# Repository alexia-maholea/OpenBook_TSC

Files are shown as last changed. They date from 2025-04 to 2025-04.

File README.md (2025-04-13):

# OpenBook E-Reader
Maholea Elena-Alexia, 333CD

## Viziune de ansamblu a proiectului
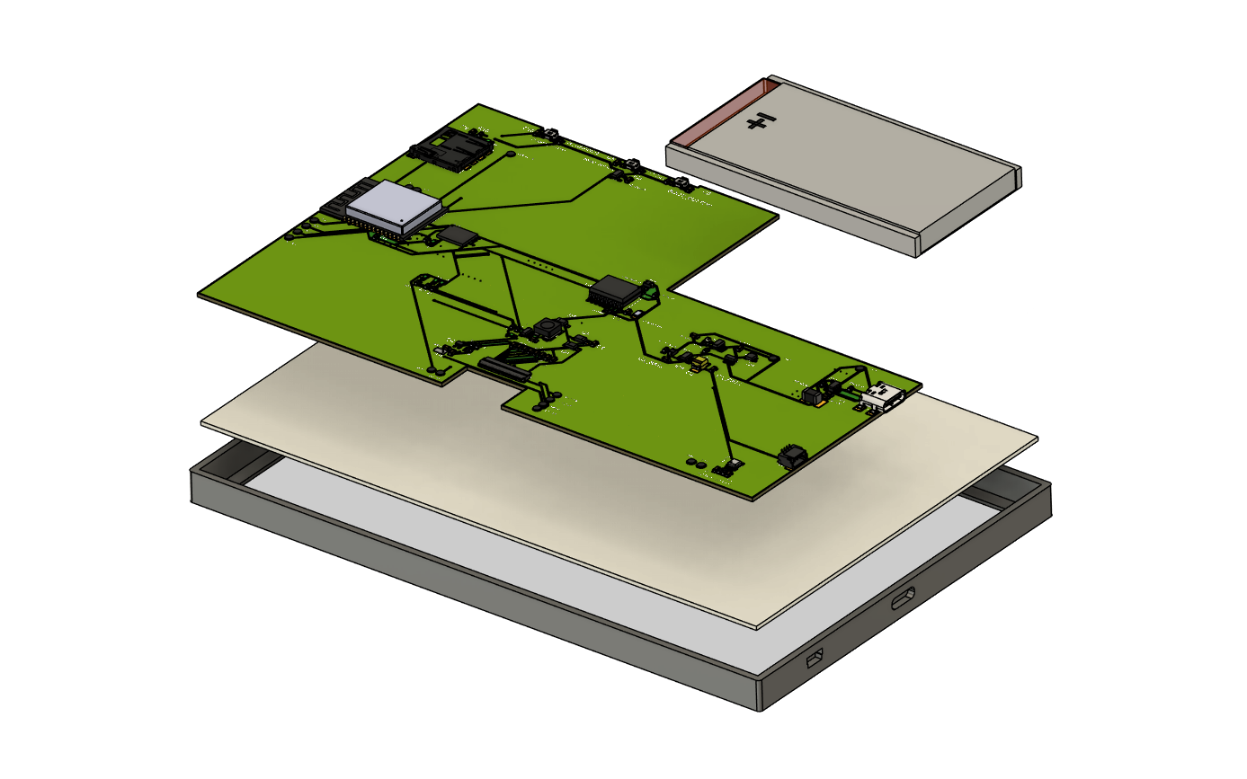
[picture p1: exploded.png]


## Schema bloc
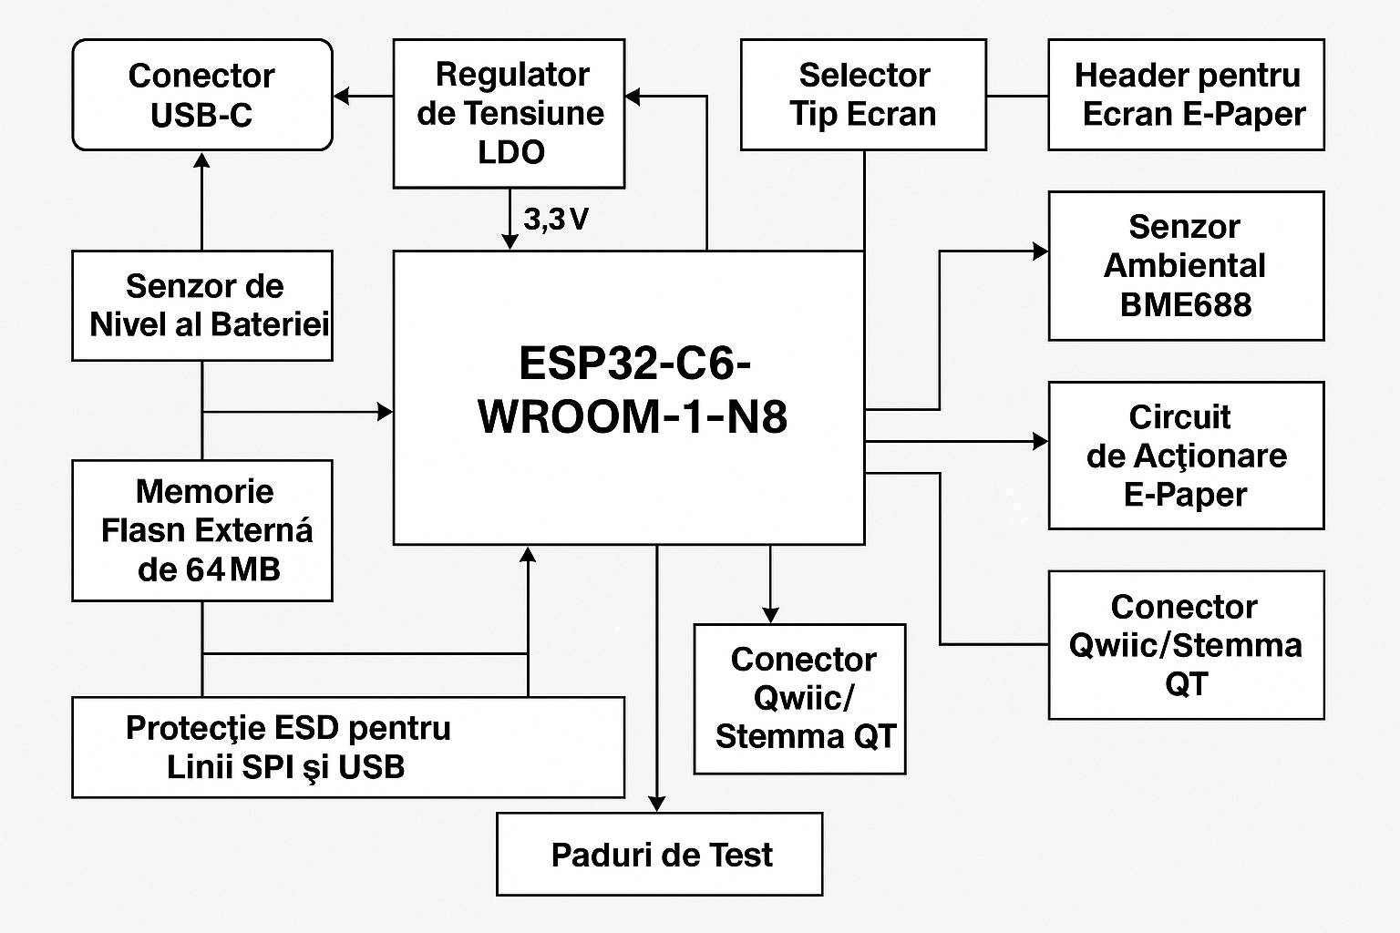
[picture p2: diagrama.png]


# Bill of Materials
|**Part Name** | **Check Price** | **DataSheet** |
|---|---|---|
|BUTTON| [Check Price](https://industry.panasonic.com/global/en/products/control/switch/light-touch/number/evqpuj02k) | [DataSheet](https://industry.panasonic.com/global/en/products/control/switch/light-touch/number/evqpuj02k) 
| ESP32_WROVER_EAGLE-LTSPICE_CC0402 | [Check Price](https://componentsearchengine.com/part-view/CC0402MRX5R5BB106/YAGEO) | [DataSheet](https://componentsearchengine.com/part-view/CC0402MRX5R5BB106/YAGEO) |
|CPH3225A | [Check Price](https://www.snapeda.com/parts/CPH3225A/Seiko+Instruments/view-part/?ref=eda) | [DataSheet](https://www.snapeda.com/parts/CPH3225A/Seiko+Instruments/view-part/?ref=eda) |
|ADAFRUIT_LEDCHIP-LED0603 | [Check Price](https://www.snapeda.com/parts/KP-1608SURCK/Kingbright/view-part/?ref=search&t=LED%200603) | [DataSheet]() |
|USBLC6-2SC6Y | [Check Price](https://www.google.com/url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) | [DataSheet](https://www.google.com/url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) |
|MBR0530 | [Check Price](https://www.google.com/url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) | [DataSheet](https://www.google.com/url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) |
|PGB1010603MR | [Check Price](https://www.snapeda.com/parts/PGB1010603MR/Littelfuse/view-part/?ref=eda) | [DataSheet](https://www.snapeda.com/parts/PGB1010603MR/Littelfuse/view-part/?ref=eda) |
| ESP32_WROVER_AVX---SD0805S020S1R0_AVX_... | [Check Price](https://eu.mouser.com/ProductDetail/KYOCERA-AVX/SD0805S020S1R0?qs=jCA%252BPfw4LHbpkAoSnwrdjw%3D%3D) | [DataSheet](https://eu.mouser.com/ProductDetail/KYOCERA-AVX/SD0805S020S1R0?qs=jCA%252BPfw4LHbpkAoSnwrdjw%3D%3D) |
| PGB1010603MR | [Check Price](https://www.snapeda.com/parts/PGB1010603MR/Littelfuse/view-part/?ref=eda) | [DataSheet](https://www.snapeda.com/parts/PGB1010603MR/Littelfuse/view-part/?ref=eda) |
|BD5229G-TR | [Check Price](https://componentsearchengine.com/part-view/BD5229G-TR/ROHM%20Semiconductor) | [DataSheet](https://componentsearchengine.com/part-view/BD5229G-TR/ROHM%20Semiconductor) |
|XC6220A331MR-G | [Check Price](https://componentsearchengine.com/part-view/XC6220A331MR-G/Torex) | [DataSheet](https://componentsearchengine.com/part-view/XC6220A331MR-G/Torex) |
|FH34SRJ-24S-0.5SH_99_ | [Check Price](https://componentsearchengine.com/part-view/XC6220A331MR-G/Torex) | [DataSheet](https://componentsearchengine.com/part-view/XC6220A331MR-G/Torex) |
|SAMACSYS_PARTS_USB4110-GF-A | [Check Price](https://componentsearchengine.com/part-view/USB4110-GF-A/GCT%20(GLOBAL%20CONNECTOR%20TECHNOLOGY)) | [DataSheet](https://componentsearchengine.com/part-view/USB4110-GF-A/GCT%20(GLOBAL%20CONNECTOR%20TECHNOLOGY)) |
|QWIIC_CONNECTORJS-1MM | #N/A | #N/A |
|112A-TAAR-R03_ATTEND | #N/A | #N/A |
|744043680IND_4828-WE-TPC_WRE | [Check Price](https://eu.mouser.com/ProductDetail/Wurth-Elektronik/744043680?qs=PGXP4M47uW6VkZq%252BkzjrHA%3D%3D) | [DataSheet](https://eu.mouser.com/ProductDetail/Wurth-Elektronik/744043680?qs=PGXP4M47uW6VkZq%252BkzjrHA%3D%3D) |
| PFMF.050.1 | [Check Price](https://www.mouser.co.uk/ProductDetail/EPCOS-TDK/B72520T0350K062?qs=dEfas%2FXlABIszF52uu7vrg%3D%3D) | [DataSheet](https://www.mouser.co.uk/ProductDetail/EPCOS-TDK/B72520T0350K062?qs=dEfas%2FXlABIszF52uu7vrg%3D%3D) |
|ESP32_WROVER_SPARKFUN-DISCRETESEMI_MOSFET_... | [Check Price](https://componentsearchengine.com/part-view/DMG2305UX-7/Diodes%20Incorporated) | [DataSheet](https://componentsearchengine.com/part-view/DMG2305UX-7/Diodes%20Incorporated) |
|SJ | [Check Price](https://grabcad.com/library/solder-jumpers-1) | [DataSheet](https://grabcad.com/library/solder-jumpers-1) |
|ESP32_WROVER_EAGLE-LTSPICE_RR0402 | [Check Price](https://componentsearchengine.com/part-view/R0402%201%25%20100%20K%20(RC0402FR-07100KL)/YAGEO) | [DataSheet](https://componentsearchengine.com/part-view/R0402%201%25%20100%20K%20(RC0402FR-07100KL)/YAGEO) |
|W25Q512JVEIQ | [Check Price](https://www.snapeda.com/parts/W25Q512JVEIQ/Winbond+Electronics/view-part/?ref=eda) | [DataSheet](https://www.snapeda.com/parts/W25Q512JVEIQ/Winbond+Electronics/view-part/?ref=eda) |
|ESP32-C6-WROOM-1-N8 | [Check Price](https://www.snapeda.com/parts/ESP32-C6-WROOM-1-N8/Espressif+Systems/view-part/?ref=eda) | [DataSheet](https://www.snapeda.com/parts/ESP32-C6-WROOM-1-N8/Espressif+Systems/view-part/?ref=eda) |
|DS3231SN# | [Check Price](https://www.snapeda.com/parts/DS3231SN%23/Analog+Devices/view-part/?ref=eda) | [DataSheet](https://www.snapeda.com/parts/DS3231SN%23/Analog+Devices/view-part/?ref=eda) |
|MAX17048G+T10 | [Check Price](https://www.snapeda.com/parts/MAX17048G+T10/Analog+Devices/view-part/?ref=eda) | [DataSheet](https://www.snapeda.com/parts/MAX17048G+T10/Analog+Devices/view-part/?ref=eda) |
|ESP32_WROVER_SPARKFUN-IC-POWER_MCP73831 | #N/A | #N/A |

## Descriere a functionalitatii componentelor hardware

OpenBook E-Reader este un dispozitiv portabil bazat pe ESP32-C3 WROOM, dotat cu un display e-ink de 1.5” (200x200 px) și alimentat de o baterie Li-Po. Proiectul optimizează consumul energetic și permite citirea cărților stocate pe card SD.

# Componente și interfețe

## Alimentare si Baterie

Sistemul poate fi alimentat fie prin portul USB-C, fie dintr-o baterie Li-Po, oferind flexibilitate in utilizare. Tensiunea de 5V furnizata de USB este folosita in paralel de doua componente:

- Un **controller de incarcare** pentru acumulatorul Li-Po
- Un **regulator LDO** care transforma cei 5V in 3.3V

Tensiunea de 3.3V alimenteaza toate componentele esentiale: microcontrolerul ESP32-C6, senzorii si afisajul. Cand sursa USB nu este conectata, bateria preia automat alimentarea intregului sistem.

## Microcontroler

La baza functionarii sta un **ESP32-C6**, responsabil cu:

- Rularea firmware-ului principal
- Conectarea la retele wireless (Wi-Fi 6 si BLE)
- Citirea datelor de la senzorii interni
- Afisarea informatiilor pe display-ul E-Paper
- Gestionarea memoriei externe: atat Flash NOR, cat si card microSD

## Senzori si RTC

Dispozitivul integreaza doi senzori conectati prin magistrala I2C:

- **BME688** – masoara temperatura, umiditatea, presiunea si compusi volatili
- **DS3231** – ceas de timp real (RTC) cu precizie ridicata

Prin I2C, datele sunt colectate rapid si trimise catre microcontroler pentru prelucrare.

## Display E-Paper

Afisajul de tip E-Paper comunica cu microcontrolerul prin interfata SPI si include urmatorii pini de control:

- `EPD_CS` (chip select)
- `EPD_DC` (data/command)
- `EPD_RST` (reset)
- `EPD_BUSY` (semnal de ocupat)

Actualizarea continutului pe ecran se face la cerere, iar consumul de energie este practic zero atunci cand imaginea este statica.

## Extensii si Stocare

Sistemul este gandit sa suporte si senzori aditionali printr-un conector compatibil **Qwiic / Stemma QT**, care extinde magistrala I2C. De asemenea, un **slot microSD** permite utilizatorului sa adauge fisiere externe (setari, loguri, eBooks etc.), iar o **memorie Flash NOR** dedicata stocheaza resurse interne precum firmware-ul, fonturile sau alte date statice.

# Mapping pini pentru EPS32-C6

| **Pin ESP32-C6** | **Nume/Funcție** | **Componentă / Scop** |
|---|---|---|
| 2 | 3V3 | Alimentare ESP32 |
| 1 | GND | Împământare |
| 15 (GPIO0) | IO/BOOT | Mod boot pentru programare |
| 3 | RESET | Reset ESP32 |
| 23 (GPIO16) | TXD0 | UART TX – comunicație serială |
| 24 (GPIO17) | RXD0 | UART RX – comunicație serială |
| 27 | MISO | SPI – date de la dispozitiv |
| 10 | MOSI | SPI – date către dispozitiv |
| 7 | SCK | SPI – semnal de ceas |
| 4 | SS/SD | SPI CS – SD card |
| 11 | EPD_CS | SPI CS – e-paper |
| 12 | FLASH_CS | SPI CS – Flash |
| 26 | EPD_BUSY | Status e-paper |
| 5 | EPD_DC | Date/Comandă e-paper |
| 21 | EPD_RST | Reset e-paper |
| 18 | EPD_3V3_C | Alimentare controlată e-paper |
| 19 | SDA | I2C – date |
| 20 | SCL | I2C – ceas |
| 17 | I2C_PW | Alimentare pentru I2C (opțional) |
| 16 | RTC_RST | Reset RTC |
| 8 | INT RTC | Interrupt RTC |
| 9 | 32KHZ | Oscilator extern RTC |
| 13, 14 | USB D-, USB D+ | Comunicare USB |
| 25 | IO/CHANGE | Pin general sau întrerupere |

# Procesul de realizare al proiectului

- In realizarea schematicului, am urmarit exact fisierul de pe OCW, iar
pentru PCB, am respectat dimensiunile si am incercat sa plasez componentele dinauntru
cat mai lizibil.

- Am realizat planurile de masa cu semnalul GND atatp e top, cat si pe bottom. Am
aplicat via stitching si am amplasat vias-urile langa antena.

- M-am folosit de autorouting pentru traseele de rutare. Am respectat cerintele de pe ocw, in legatura cu dimensiunea firelor de cupru, respectiv minim 0.30mm pentru traseele de putere si 0.15 pentru restul.

- TP-urile au fost amplasate dupa cum am considerat ca ar fi mai eficient pentru rutare
pentru a fi aproape de componentele la care sunt conectate

- Dupa ce am trecut in 3D, am adaugat componentele si le-am creat/editat modelele 3D cat sa fie asezate corespunzator pe placa.

- Pentru a scapa de erorile aparute, am efectuat diferite actiuni:
    - Pentru erorile de tip SMD-Hole, am dat Approve dupa cum ni s-a specificat
    - Pentru alte tipuri de erori, a fost nevoie sa modific footprint-ul componentelor sau sa mut firele de pe placa

- Am realizat si modele 3D pentru baterie si display, conform documentelor oferite. Am
incercat pe cat mai mult sa respect dimensiunile pentru a nu avea probleme la amplasare.

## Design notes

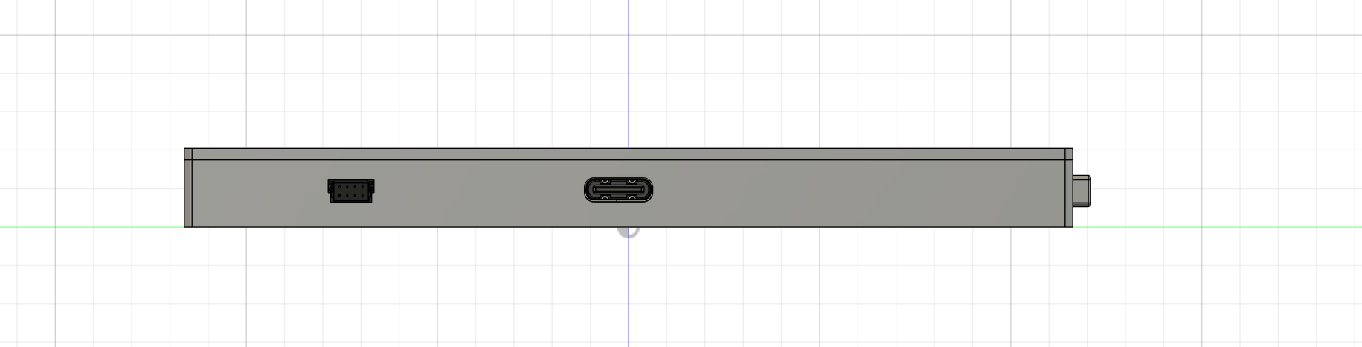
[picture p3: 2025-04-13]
Images/right.png

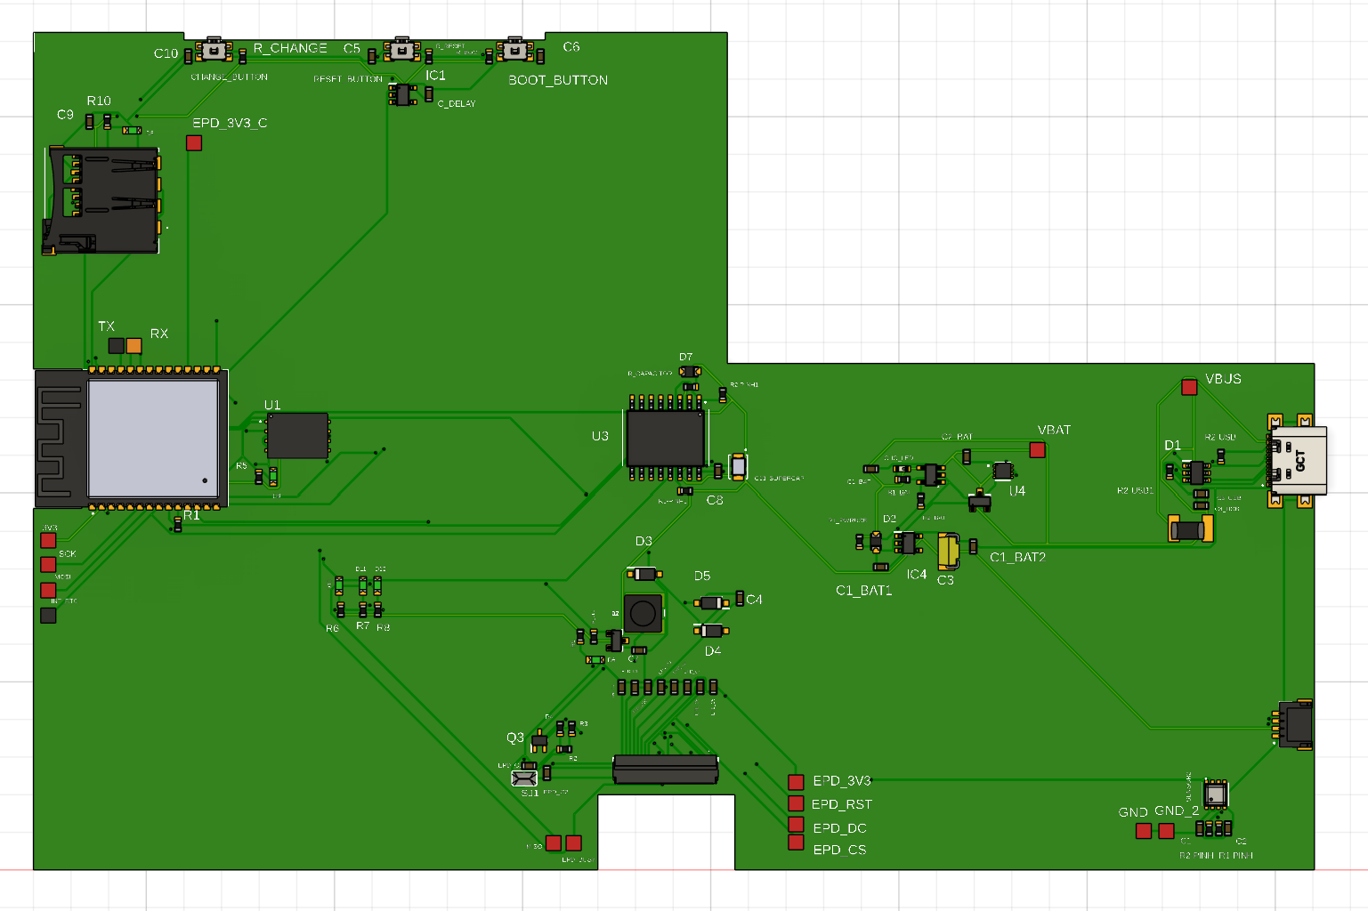
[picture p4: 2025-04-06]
Images/placuta2.png

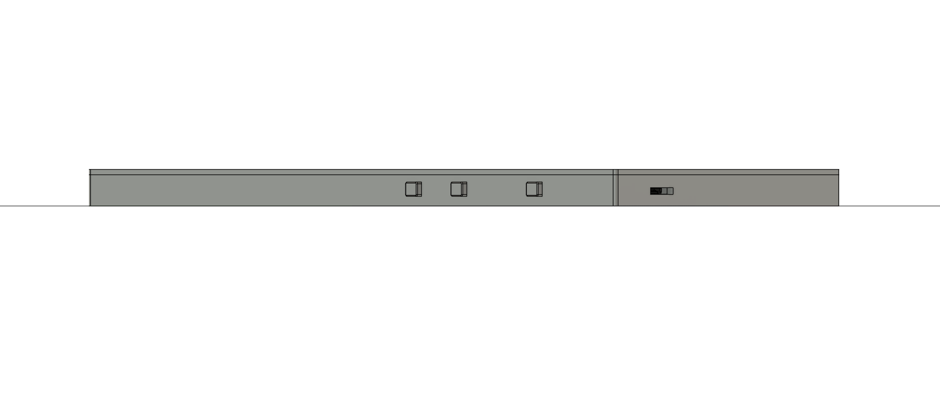
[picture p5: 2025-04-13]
Images/angle.png

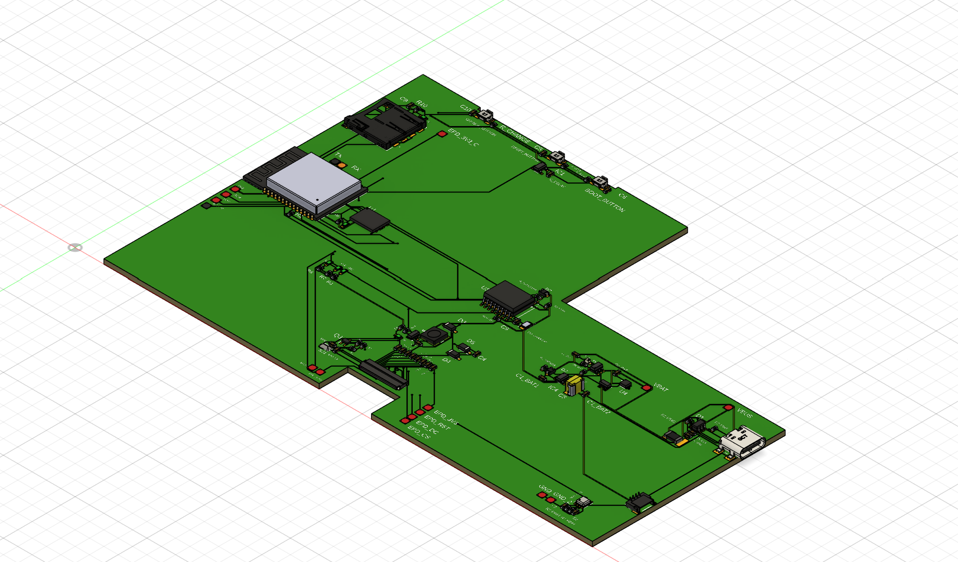
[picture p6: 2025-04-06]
Images/placuta.png

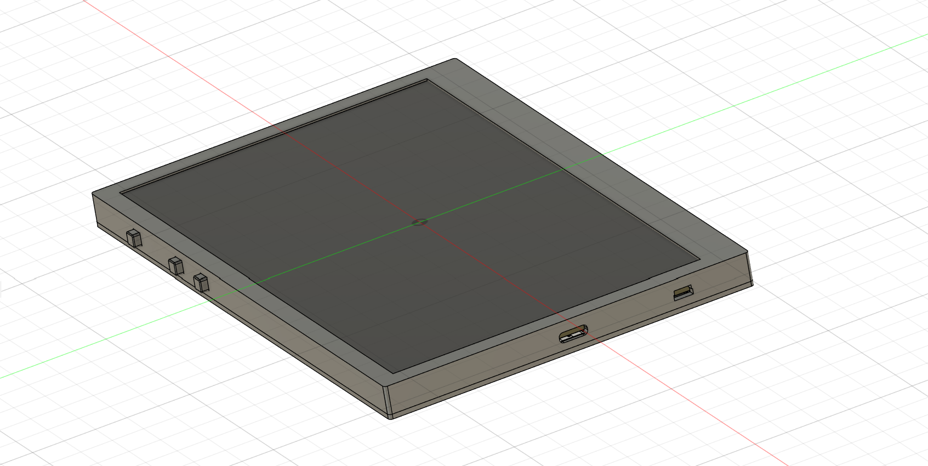
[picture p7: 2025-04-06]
Images/dispozitiv.png

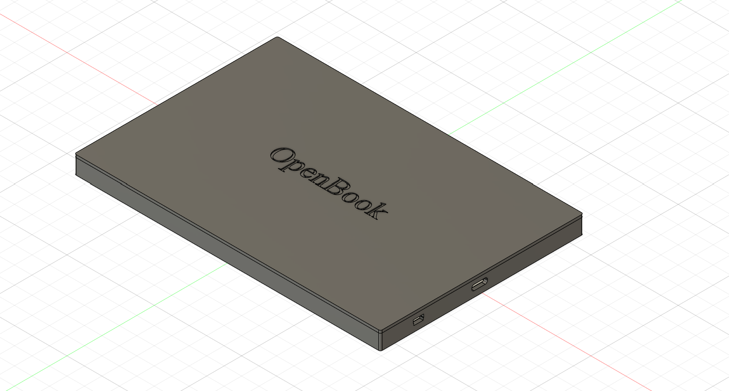
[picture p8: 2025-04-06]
Images/dispozitiv2.png

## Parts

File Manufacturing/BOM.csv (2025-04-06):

Qty | Value | Device | Package | Parts | Description | ARROW_PART_NUMBER | ARROW_PRICE-STOCK | AVAILABILITY | CENTROID_NOT_SPECIFIED | CHECK_PRICES | COPYRIGHT | DATASHEET | DESCRIPTION | DIGIKEY_DESCRIPTION | DIGIKEY_PART_NUMBER | HEIGHT | LEAD_FREE | MANUFACTURER_NAME | MANUFACTURER_PART_NUMBER | MF | MFR_NAME | MOUSER_PART_NUMBER | MOUSER_PRICE-STOCK | MOUSER_TESTING_PART_NUMBER | MOUSER_TESTING_PRICE-STOCK | MP | MPN | PACKAGE | POPULARITY | PREFIX | PRICE | PROD_ID | PURCHASE-URL | ROHS | SNAPEDA_LINK | SPICEMODEL | SPICEPREFIX | TEMPERATURE_RANGE_HIGH | TEMPERATURE_RANGE_LOW | TP_SIGNAL_NAME | VALUE
1 |  | ADAFRUIT_LEDCHIP-LED0603 | ADAFRUIT_CHIP-LED0603 | CHG_LED | LED
1 |  | SJ | SJ | SJ1 | SMD solder JUMPER |  |  |  |  |  |  |  |  |  |  |  |  |  |  |  |  |  |  |  |  |  |  |  | 3
1 | 0.1uF/50V | EAGLE-LTSPICE_CC0402 | EAGLE-LTSPICE_C0402 | EPD_C5 | CAPACITOR, European symbol |  |  |  |  |  |  |  |  |  |  |  |  |  |  |  |  |  |  |  |  |  |  |  |  |  |  |  |  |  |  | NONE | C
1 | 0.47 | ESP32_WROVER_EAGLE-LTSPICE_RR0402 | ESP32_WROVER_EAGLE-LTSPICE_R0402 | R3 | RESISTOR, European symbol |  |  |  |  |  |  |  |  |  |  |  |  |  |  |  |  |  |  |  |  |  |  |  |  |  |  |  |  |  |  | NONE | R
1 | 100K | ESP32_WROVER_EAGLE-LTSPICE_RR0402 | ESP32_WROVER_EAGLE-LTSPICE_R0402 | R1_PWRUSB | RESISTOR, European symbol |  |  |  |  |  |  |  |  |  |  |  |  |  |  |  |  |  |  |  |  |  |  |  |  |  |  |  |  |  |  | NONE | R
8 | 100nF | EAGLE-LTSPICE_CC0402 | EAGLE-LTSPICE_C0402 | C1, C2, C4_USB, C6, C8, C9, C10, C_DELAY | CAPACITOR, European symbol |  |  |  |  |  |  |  |  |  |  |  |  |  |  |  |  |  |  |  |  |  |  |  |  |  |  |  |  |  |  | NONE | C
1 | 100uF TANT | RCL_CPOL-EUCT3528 | RCL_CT3528 | C3 | POLARIZED CAPACITOR, European symbol |  |  |  |  |  |  |  |  |  |  |  |  |  |  |  |  |  |  |  |  |  |  |  | 0 |  |  |  |  |  |  |  | C
16 | 10K | ESP32_WROVER_EAGLE-LTSPICE_RR0402 | ESP32_WROVER_EAGLE-LTSPICE_R0402 | R1, R1-PINH, R1-PINH1, R2-PINH, R2-PINH1, R4, R5, R6, R7, R8, R9, R10, R_BOOT, R_CHANGE, R_CL1, R_RESET | RESISTOR, European symbol |  |  |  |  |  |  |  |  |  |  |  |  |  |  |  |  |  |  |  |  |  |  |  |  |  |  |  |  |  |  | NONE | R
1 | 10uF | EAGLE-LTSPICE_CC0402 | EAGLE-LTSPICE_C0402 | C7 | CAPACITOR, European symbol |  |  |  |  |  |  |  |  |  |  |  |  |  |  |  |  |  |  |  |  |  |  |  |  |  |  |  |  |  |  | NONE | C
1 | 112A-TAAR-R03_ATTEND | 112A-TAAR-R03_ATTEND | 112ATAARR03ATTEND | J4 | Micro SD Card Socket, Push-Push Type, Top Mount, SMT, H=1.83mm, 10u |  |  |  |  |  |  |  | Micro SD Card Socket | Push-Push Type | Top Mount | SMT | H=1.83mm | 10u |  |  | 1.9mm |  | ATTEND | 112A-TAAR-R03 ATTEND
1 | 15 | ESP32_WROVER_EAGLE-LTSPICE_RR0402 | ESP32_WROVER_EAGLE-LTSPICE_R0402 | R_CAPACITOR | RESISTOR, European symbol |  |  |  |  |  |  |  |  |  |  |  |  |  |  |  |  |  |  |  |  |  |  |  |  |  |  |  |  |  |  | NONE | R
1 | 1uF | EAGLE-LTSPICE_CC0402 | EAGLE-LTSPICE_C0402 | C5 | CAPACITOR, European symbol |  |  |  |  |  |  |  |  |  |  |  |  |  |  |  |  |  |  |  |  |  |  |  |  |  |  |  |  |  |  | NONE | C
9 | 1uF/50V | EAGLE-LTSPICE_CC0402 | EAGLE-LTSPICE_C0402 | EPD_C1, EPD_C2, EPD_C6, EPD_C7, EPD_C8, EPD_C9, EPD_C10, EPD_C11, EPD_C12 | CAPACITOR, European symbol |  |  |  |  |  |  |  |  |  |  |  |  |  |  |  |  |  |  |  |  |  |  |  |  |  |  |  |  |  |  | NONE | C
1 | 2.2 | ESP32_WROVER_EAGLE-LTSPICE_RR0402 | ESP32_WROVER_EAGLE-LTSPICE_R0402 | R2 | RESISTOR, European symbol |  |  |  |  |  |  |  |  |  |  |  |  |  |  |  |  |  |  |  |  |  |  |  |  |  |  |  |  |  |  | NONE | R
1 | 200 | ESP32_WROVER_EAGLE-LTSPICE_RR0402 | ESP32_WROVER_EAGLE-LTSPICE_R0402 | R1_BAT | RESISTOR, European symbol |  |  |  |  |  |  |  |  |  |  |  |  |  |  |  |  |  |  |  |  |  |  |  |  |  |  |  |  |  |  | NONE | R
2 | 20V/4.2A/52mO/1.4W | ESP32_WROVER_SPARKFUN-DISCRETESEMI_MOSFET_PCH-DMG2305UX-7 | ESP32_WROVER_SPARKFUN-DISCRETESEMI_SOT23-3 | Q1, Q2 | P-channel MOSFETs |  |  |  |  |  |  |  |  |  |  |  |  |  |  |  |  |  |  |  |  |  |  |  |  |  |  | TRAN-14388 |  |  |  |  |  |  |  |  | 20V/4.2A/52mO/1.4W
1 | 2K | ESP32_WROVER_EAGLE-LTSPICE_RR0402 | ESP32_WROVER_EAGLE-LTSPICE_R0402 | R2_BAT | RESISTOR, European symbol |  |  |  |  |  |  |  |  |  |  |  |  |  |  |  |  |  |  |  |  |  |  |  |  |  |  |  |  |  |  | NONE | R
5 | 4.7uF | EAGLE-LTSPICE_CC0402 | EAGLE-LTSPICE_C0402 | C1_BAT, C1_BAT1, C1_BAT2, C2_BAT, C5_USB | CAPACITOR, European symbol |  |  |  |  |  |  |  |  |  |  |  |  |  |  |  |  |  |  |  |  |  |  |  |  |  |  |  |  |  |  | NONE | C
1 | 4.7uF/25V | EAGLE-LTSPICE_CC0402 | EAGLE-LTSPICE_C0402 | C4 | CAPACITOR, European symbol |  |  |  |  |  |  |  |  |  |  |  |  |  |  |  |  |  |  |  |  |  |  |  |  |  |  |  |  |  |  | NONE | C
2 | 5k1 | ESP32_WROVER_EAGLE-LTSPICE_RR0402 | ESP32_WROVER_EAGLE-LTSPICE_R0402 | R2-USB, R2-USB1 | RESISTOR, European symbol |  |  |  |  |  |  |  |  |  |  |  |  |  |  |  |  |  |  |  |  |  |  |  |  |  |  |  |  |  |  | NONE | R
1 | 68uH | 744043680IND_4828-WE-TPC_WRE | IND_4828-WE-TPC_WRE | L1 |  |  |  |  |  |  | Copyright (C) 2024 Ultra Librarian. All rights reserved. |  |  |  |  |  |  |  | 744043680 |  | Wurth Electronics
1 | BD5229G-TR | BD5229G-TR | SOT95P280X125-5N | IC1 | Voltage Detector with Adjustable Delay Time: CMOS processes are utilized to develop high precision, low current consumption CMOS reset ICs that allow arbitrary setting of the delay time. The extensive lineup includes both Nch Open Drain and CMOS output types in a wide range of detection voltages (from 2.3V to 6.0V, in 0.1V steps), enabling selection of the ideal solution based on customer requirements. In addition, the entire series is of course both lead-free and RoHS-compliant. |  |  |  |  |  |  |  | Voltage Detector with Adjustable Delay Time: CMOS processes are utilized to develop high precision | low current consumption CMOS reset ICs that allow arbitrary setting of the delay time. The extensive lineup includes both Nch Open Drain and CMOS output types in a wide range of detection voltages (from 2.3V to 6.0V | in 0.1V steps) | enabling selection of the ideal solution based on customer requirements. In addition | the entire series is of course both lead-free and RoHS-compliant. |  |  | 1.25mm |  | ROHM Semiconductor | BD5229G-TR |  |  | 755-BD5229G-TR | https://www.mouser.co.uk/ProductDetail/ROHM-Semiconductor/BD5229G-TR?qs=4kLU8WoGk0vvnhrrYwdszw%3D%3D
3 | BUTTON_CUSYOMV1 | BUTTON_CUSYOMV1 | MYBUTTON | BOOT_BUTTON, CHANGE_BUTTON, RESET_BUTTON
1 | CPH3225A | CPH3225A | CAPCP3225X100N | C10_SUPERCAP | Cap 0.011F 3.3V 1210 Flat Check availability |  |  | Not in stock |  | https://www.snapeda.com/parts/CPH3225A/Seiko+Instruments/view-part/?ref=eda |  |  | 11 mF (EDLC) Supercapacitor 3.3 V 1210 (3225 Metric) - - |  |  |  |  |  |  | Seiko Instruments |  |  |  |  |  | CPH3225A |  | 1210 Seiko |  |  | None |  | https://www.snapeda.com/api/url_track_click_mouser/?unipart_id=562593&manufacturer=Seiko Instruments&part_name=CPH3225A&search_term=None |  | https://www.snapeda.com/parts/CPH3225A/Seiko+Instruments/view-part/?ref=snap
1 | DS3231SN# | DS3231SN# | SOIC127P1032X265-16N | U3 | Real Time Clock Serial 16-Pin SOIC W T/R Check availability |  |  | In Stock |  | https://www.snapeda.com/parts/DS3231SN%23/Analog+Devices/view-part/?ref=eda |  |  | Extremely Accurate I²C-Integrated RTC/TCXO/Crystal |  |  |  |  |  |  | Analog Devices |  |  |  |  |  | DS3231SN# |  | SOIC-16 Maxim |  |  | None |  | https://www.snapeda.com/api/url_track_click_mouser/?unipart_id=99048&manufacturer=Analog Devices&part_name=DS3231SN#&search_term=None |  | https://www.snapeda.com/parts/DS3231SN%23/Analog+Devices/view-part/?ref=snap
1 | ESP32-C6-WROOM-1-N8 | ESP32-C6-WROOM-1-N8 | XCVR_ESP32-C6-WROOM-1-N8 | U2 | Check availability |  |  | In Stock |  | https://www.snapeda.com/parts/ESP32-C6-WROOM-1-N8/Espressif+Systems/view-part/?ref=eda |  |  | Multiprotocol Modules ESP32-C6 module | Wi-Fi 6 in 2.4 GHz band | Bluetooth 5 | Zigbee 3.0 and Thread. ESP34-WROOM Compatible - ENGINEERING SAMPLE |  |  |  |  |  |  | Espressif Systems |  |  |  |  |  | ESP32-C6-WROOM-1-N8 |  | None |  |  | None |  |  |  | https://www.snapeda.com/parts/ESP32-C6-WROOM-1-N8/Espressif+Systems/view-part/?ref=snap
1 | ESP32C6_VARISTORCN1812 | ESP32C6_VARISTORCN1812 | ESP32C6_VARISTOR_CT/CN1812 | PFMF.050.1 | VARISTOR |  |  |  |  |  |  |  |  |  |  |  |  |  |  |  |  |  |  |  |  |  |  |  | 0
2 | ESP32_WROVER_AVX---SD0805S020S1R0_AVX_SD0805S020S1R0_0_0AVX_SD0805S020S1R0_0_0 | ESP32_WROVER_AVX---SD0805S020S1R0_AVX_SD0805S020S1R0_0_0AVX_SD0805S020S1R0_0_0 | ESP32_WROVER_AVX---SD0805S020S1R0_AVX_SD0805S020S1R0_0 | D2, D7 | Schottky Barrier Rectifier Diode |  |  |  | No |  |  | http://datasheets.avx.com/schottky.pdf |  | DIODE SCHOTTKY 20V 1A 0805 | 478-7800-1-ND |  | yes |  |  | AVX |  | 581-SD0805S020S1R0 |  |  |  |  |  | 0805 (2012 metric) |  | D |  |  |  | yes |  |  |  | +125°C | -55°C
1 | ESP32_WROVER_BME680_BME680 | ESP32_WROVER_BME680_BME680 | ESP32_WROVER_BME680_PSON80P300X300X100-8N | SENSOR2 | Integrated Environmental Unit |  |  | Unavailable |  |  |  |  | Integrated Environmental Unit |  |  |  |  |  |  | Bosch Sensortec |  |  |  |  |  | BME680 |  | LGA-8 Bosch Tools |  |  | None
1 | ESP32_WROVER_SPARKFUN-IC-POWER_MCP73831 | ESP32_WROVER_SPARKFUN-IC-POWER_MCP73831 | ESP32_WROVER_SPARKFUN-IC-POWER_SOT23-5 | MCP73831 | MCP73831T Li-Ion, Li-Pol Controller |  |  |  |  |  |  |  |  |  |  |  |  |  |  |  |  |  |  |  |  |  |  |  |  |  |  | IC-09995
1 | FH34SRJ-24S-0.5SH_99_ | FH34SRJ-24S-0.5SH_99_ | FH34SRJ24S05SH99 | J1 | (0.50mm) Surface Mount, Right Angle |  |  |  |  |  |  |  | 24 Position FFC | FPC Connector Contacts | (0.50mm) Surface Mount | Right Angle |  |  | 1.1mm |  | Hirose | FH34SRJ-24S-0.5SH(99) |  |  | 798-FH34SRJ24S05SH99 | https://www.mouser.co.uk/ProductDetail/Hirose-Connector/FH34SRJ-24S-0.5SH99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
1 | MAX17048G+T10 | MAX17048G+T10 | SON50P200X200X80-9N | U4 | Check availability |  |  | In Stock |  | https://www.snapeda.com/parts/MAX17048G+T10/Analog+Devices/view-part/?ref=eda |  |  | 3µA 1-Cell/2-Cell Fuel Gauge with ModelGauge |  |  |  |  |  |  | Analog Devices |  |  |  |  |  | MAX17048G+T10 |  | TDFN-8 Maxim |  |  | None |  | https://www.snapeda.com/api/url_track_click_mouser/?unipart_id=329239&manufacturer=Analog Devices&part_name=MAX17048G+T10&search_term=None |  | https://www.snapeda.com/parts/MAX17048G+T10/Analog+Devices/view-part/?ref=snap
3 | MBR0530 | MBR0530 | SOD3716X135N | D3, D4, D5 | ON SEMICONDUCTOR - MBR0530 - DIODE, SCHOTTKY, 0.5A, 30V, SOD-123 |  |  | In Stock |  | https://www.snapeda.com/parts/MBR0530/Onsemi/view-part/?ref=eda |  |  | Diode Schottky 30 V 500mA Surface Mount SOD-123 |  |  |  |  |  |  | ON Semiconductor |  |  |  |  |  | MBR0530 |  | SOD-123-2 ON Semiconductor |  |  | None |  | https://www.snapeda.com/api/url_track_click_mouser/?unipart_id=179458&manufacturer=ON Semiconductor&part_name=MBR0530&search_term=None |  | https://www.snapeda.com/parts/MBR0530/Onsemi/view-part/?ref=snap
6 | PGB1010603MR | PGB1010603MR | DIOC1608X36N | D6, D8, D9, D10, D11, D12 | Check availability |  |  | In Stock |  | https://www.snapeda.com/parts/PGB1010603MR/Littelfuse/view-part/?ref=eda |  |  | 150V (Typ) Clamp - Ipp Tvs Diode Surface Mount 0603 (1608 Metric) |  |  |  |  |  |  | Littelfuse Inc. |  |  |  |  |  | PGB1010603MR |  | 0603 Littelfuse Inc. |  |  | None |  | https://www.snapeda.com/api/url_track_click_mouser/?unipart_id=5659453&manufacturer=Littelfuse Inc.&part_name=PGB1010603MR&search_term=None |  | https://www.snapeda.com/parts/PGB1010603MR/Littelfuse/view-part/?ref=snap
1 | QWIIC_RIGHT_ANGLE | QWIIC_CONNECTORJS-1MM | JST04_1MM_RA | J3 | SparkFun I2C Standard Qwiic Connector |  |  |  |  |  |  |  |  |  |  |  |  |  |  |  |  |  |  |  |  |  |  |  |  |  |  | CONN-13694 |  |  |  |  |  |  |  |  | QWIIC_RIGHT_ANGLE
1 | SAMACSYS_PARTS_USB4110-GF-A | SAMACSYS_PARTS_USB4110-GF-A | SAMACSYS_PARTS_USB4110GFA | J2 | CONN USB 2.0 TYPE-C R/A SMT |  |  |  |  |  |  |  | CONN USB 2.0 TYPE-C R/A SMT |  |  | 3.26mm |  | GCT (GLOBAL CONNECTOR TECHNOLOGY) | USB4110-GF-A |  |  | 640-USB4110-GF-A | https://www.mouser.co.uk/ProductDetail/GCT/USB4110-GF-A?qs=KUoIvG%2F9IlYiZvIXQjyJeA%3D%3D
1 | SI1308EDL-T1-GE3 | SI1308EDL-T1-GE3 | SOT65P210X110-3N | Q3 | MOSFET N-Ch 30V 1.5A TrenchFET SC70 Vishay Si1308EDL-T1-GE3 N-channel MOSFET Transistor, 1.5 A, 30 V, 3-Pin SC-70 |  |  | In Stock |  | https://www.snapeda.com/parts/SI1308EDL-T1-GE3/Vishay+Siliconix/view-part/?ref=eda |  |  | Si1308EDL-T1-GE3 N-channel MOSFET Transistor | 1.5 A | 30 V | 3-Pin SC-70 | Siliconix / Vishay SI1308EDL-T1-GE3 |  |  |  |  |  |  | Vishay Siliconix |  |  |  |  |  | SI1308EDL-T1-GE3 |  | SOT-323 Vishay Semiconductor |  |  | None |  | https://www.snapeda.com/api/url_track_click_mouser/?unipart_id=274603&manufacturer=Vishay Siliconix&part_name=SI1308EDL-T1-GE3&search_term=None |  | https://www.snapeda.com/parts/SI1308EDL-T1-GE3/Vishay+Siliconix/view-part/?ref=snap
17 | TPTP20R | TPTP20R | TP20R | 3V3, EPD_3V3, EPD_3V3_C, EPD_BUSY, EPD_CS, EPD_DC, EPD_RST, GND, GND_2, INT_RTC, MISO, MOSI, RX, SCK, TX, VBAT, VBUS | Test pad |  |  |  |  |  |  |  |  |  |  |  |  |  |  |  |  |  |  |  |  |  |  |  | 2
1 | USBLC6-2SC6Y | USBLC6-2SC6Y | SOT95P280X145-6N | D1 | Low Cap. ESD Protection Auto SOT-23-6 STMicroelectronics USBLC6-2SC6Y, Dual Uni-Directional TVS Diode Array, 6-Pin SOT-23 |  |  | In Stock |  | https://www.snapeda.com/parts/USBLC6-2SC6Y/STMicroelectronics/view-part/?ref=eda |  |  | 17V Clamp 5A (8/20µs) Ipp Tvs Diode Surface Mount SOT-23-6 |  |  |  |  |  |  | STMicroelectronics |  |  |  |  |  | USBLC6-2SC6Y |  | SOT-23-6 STMicroelectronics |  |  | None |  |  |  | https://www.snapeda.com/parts/USBLC6-2SC6Y/STMicroelectronics/view-part/?ref=snap
1 | W25Q512JVEIQ | W25Q512JVEIQ | SON127P600X800X80-9N | U1 | Check availability |  |  | In Stock |  | https://www.snapeda.com/parts/W25Q512JVEIQ/Winbond+Electronics/view-part/?ref=eda |  |  | FLASH - NOR Memory IC 512Mb (64M x 8) SPI - Quad I/O 133 MHz 8-WSON (8x6) |  |  |  |  |  |  | Winbond Electronics |  |  |  |  |  | W25Q512JVEIQ |  | Package |  |  | None |  |  |  | https://www.snapeda.com/parts/W25Q512JVEIQ/Winbond+Electronics/view-part/?ref=snap
1 | XC6220A331MR-G | XC6220A331MR-G | SOT95P280X120-5N | IC4 | LDO Voltage Regulators |  |  |  |  |  |  |  | LDO Voltage Regulators |  |  | 1.2mm |  | Torex | XC6220A331MR-G |  |  | 865-XC6220A331MR-G | https://www.mouser.co.uk/ProductDetail/Torex-Semiconductor/XC6220A331MR-G?qs=AsjdqWjXhJ8ZSWznL1J0gg%3D%3D

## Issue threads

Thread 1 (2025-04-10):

Missing "Exploded View" .step file and overview images.

Nastyst16, 2025-04-10:
## The Mechanical folder is expected to include a .step file representing the full 3D assembly (PCB, battery, display, and enclosure) with an exploded view for clarity.
#### Here is an example of what it should look like:
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

Closed 2025-04-13.

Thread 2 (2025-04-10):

Unfilled PCB areas within GND polygon

Nastyst16, 2025-04-10:
## The PCB contains unfilled areas within the GND polygon, resulting in sections where the copper pour is missing.

<p align="center">
  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
</p>

### Additionally, consider adding stitching vias between ground regions

Closed 2025-04-13.

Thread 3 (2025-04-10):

Missplaced 3D components

Nastyst16, 2025-04-10:
### Missplaced 3D components:
- C3: Polarized Capacitor
- Inductor: 744043680

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

### Please verify the placement of these components in the 3D model and ensure they are correctly aligned with their respective footprints and orientations.

Closed 2025-04-13.

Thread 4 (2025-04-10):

Improved Readme

Nastyst16, 2025-04-10:
### In the current Bill of Materials (BoM), multiple entries for resistors and components (such as R1, R2, etc.) have #N/A for part details. Instead of repeating #N/A for each resistor, it would be more efficient to group them together under a single part name or use a placeholder for all resistors in general.

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

### Please update the BoM to use a more concise approach, grouping similar parts under a single label where appropriate. This will improve readability and simplify the reading.

Closed 2025-04-13.

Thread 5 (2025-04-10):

Misalignment of Board Ports with Enclosure Holes

Nastyst16, 2025-04-10:
### It appears that the ports on the PCB are not properly aligned with the corresponding holes in the enclosure. This misalignment may cause issues during assembly and limit the accessibility of the ports.

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

### Please review the positions of the ports on the PCB and adjust them to ensure proper alignment with the holes in the enclosure. Ensuring correct placement will help avoid potential assembly issues and improve the overall design.

Closed 2025-04-13.

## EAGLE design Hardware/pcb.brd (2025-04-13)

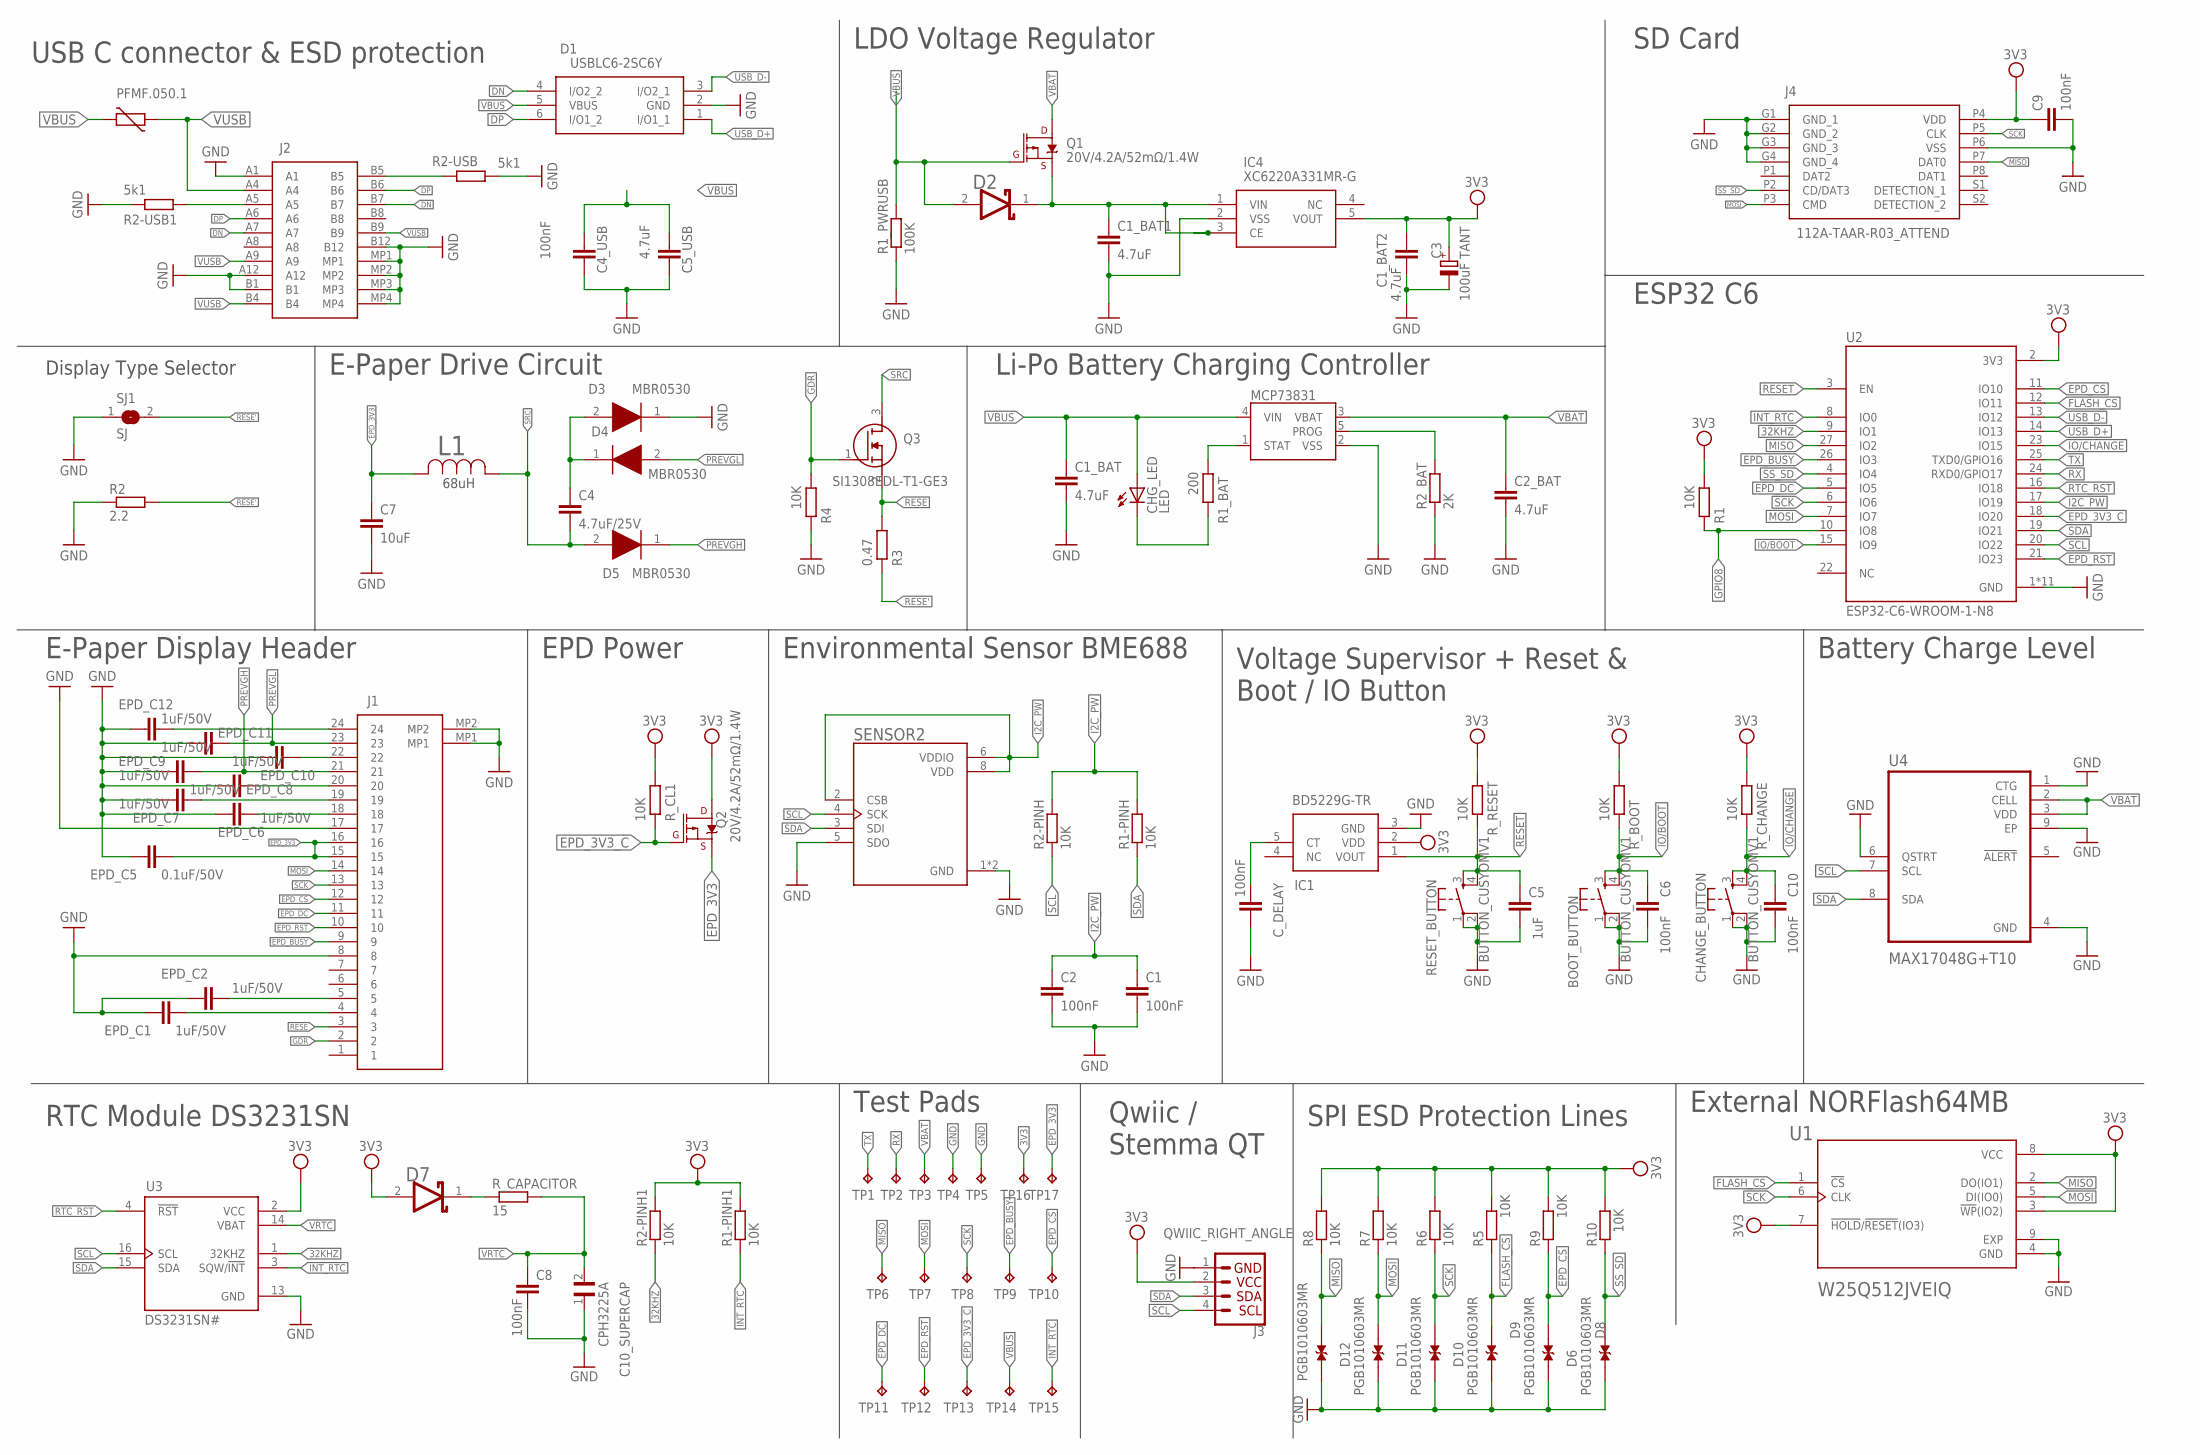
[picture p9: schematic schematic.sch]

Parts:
BOOT_BUTTON: BUTTON_CUSYOMV1; MYBUTTON
C1, C2, C4_USB, C6, C8, C9, C10: 100nF; EAGLE-LTSPICE_C0402
C1_BAT, C1_BAT1, C1_BAT2, C2_BAT, C5_USB: 4.7uF; EAGLE-LTSPICE_C0402
C3: 100uF TANT; RCL_CT3528
C4: 4.7uF/25V; EAGLE-LTSPICE_C0402
C5: 1uF; EAGLE-LTSPICE_C0402
C7: 10uF; EAGLE-LTSPICE_C0402
C10_SUPERCAP: CPH3225A; CAPCP3225X100N
CHANGE_BUTTON: BUTTON_CUSYOMV1; MYBUTTON
CHG_LED: LED; ADAFRUIT_CHIP-LED0603
C_DELAY: 100nF; EAGLE-LTSPICE_C0402
D1: USBLC6-2SC6Y; SOT95P280X145-6N
D2, D7: ESP32_WROVER_AVX---SD0805S020S1R0_AVX_SD0805S020S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; ESP32_WROVER_AVX---SD0805S020S1R0_AVX_SD0805S020S1R0_0
D3, D4, D5: MBR0530; SOD3716X135N
D6, D8, D9, D10, D11, D12: PGB1010603MR; DIOC1608X36N
EPD_C1, EPD_C2, EPD_C6, EPD_C7, EPD_C8, EPD_C9, EPD_C10, EPD_C11, EPD_C12: 1uF/50V; EAGLE-LTSPICE_C0402
EPD_C5: 0.1uF/50V; EAGLE-LTSPICE_C0402
IC1: BD5229G-TR; SOT95P280X125-5N
IC4: XC6220A331MR-G; SOT95P280X120-5N
J1: FH34SRJ-24S-0.5SH_99_; FH34SRJ24S05SH99
J2: SAMACSYS_PARTS_USB4110-GF-A; SAMACSYS_PARTS_USB4110GFA
J3: QWIIC_RIGHT_ANGLE; JST04_1MM_RA
J4: 112A-TAAR-R03_ATTEND; 112ATAARR03ATTEND
L1: 68uH; IND_4828-WE-TPC_WRE
MCP73831: ESP32_WROVER_SPARKFUN-IC-POWER_MCP73831; ESP32_WROVER_SPARKFUN-IC-POWER_SOT23-5
PFMF.050.1: ESP32C6_VARISTORCN1812; ESP32C6_VARISTOR_CT/CN1812
Q1, Q2: 20V/4.2A/52mΩ/1.4W; ESP32_WROVER_SPARKFUN-DISCRETESEMI_SOT23-3
Q3: SI1308EDL-T1-GE3; SOT65P210X110-3N
R1, R1-PINH, R1-PINH1, R2-PINH, R2-PINH1, R4, R5, R6, R7, R8, R9, R10: 10K; ESP32_WROVER_EAGLE-LTSPICE_R0402
R1_BAT: 200; ESP32_WROVER_EAGLE-LTSPICE_R0402
R1_PWRUSB: 100K; ESP32_WROVER_EAGLE-LTSPICE_R0402
R2: 2.2; ESP32_WROVER_EAGLE-LTSPICE_R0402
R2-USB, R2-USB1: 5k1; ESP32_WROVER_EAGLE-LTSPICE_R0402
R2_BAT: 2K; ESP32_WROVER_EAGLE-LTSPICE_R0402
R3: 0.47; ESP32_WROVER_EAGLE-LTSPICE_R0402
RESET_BUTTON: BUTTON_CUSYOMV1; MYBUTTON
R_BOOT: 10K; ESP32_WROVER_EAGLE-LTSPICE_R0402
R_CAPACITOR: 15; ESP32_WROVER_EAGLE-LTSPICE_R0402
R_CHANGE: 10K; ESP32_WROVER_EAGLE-LTSPICE_R0402
R_CL1: 10K; ESP32_WROVER_EAGLE-LTSPICE_R0402
R_RESET: 10K; ESP32_WROVER_EAGLE-LTSPICE_R0402
SENSOR2: ESP32_WROVER_BME680_BME680; ESP32_WROVER_BME680_PSON80P300X300X100-8N
SJ1: SJ
TP1, TP2, TP3, TP4, TP5, TP6, TP7, TP8, TP9, TP10, TP11, TP12, TP13, TP14, TP15, TP16, TP17: TPTP20R; TP20R
U1: W25Q512JVEIQ; SON127P600X800X80-9N
U2: ESP32-C6-WROOM-1-N8; XCVR_ESP32-C6-WROOM-1-N8
U3: DS3231SN#; SOIC127P1032X265-16N
U4: MAX17048G+T10; SON50P200X200X80-9N

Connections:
3V3: C1_BAT2.1, C3.+, C9.1, D7.2 (ANODE), IC1.2 (VDD), IC4.5 (VOUT), J3.2, J4.P4 (VDD), Q2.3 (D), R1.2, R1-PINH1.2, R2-PINH1.2, R5.2, R6.2, R7.2, R8.2, R9.2, R10.2, R_BOOT.2, R_CHANGE.2, R_CL1.2, R_RESET.2, TP16.TP, U1.3 (!WP!(IO2)), U1.7 (!HOLD!/!RESET!(IO3)), U1.8 (VCC), U2.2 (3V3), U3.2 (VCC)
32KHZ: R2-PINH1.1, U2.9 (IO1), U3.1 (32KHZ)
DN: D1.4 (I/O2_2), J2.A7, J2.B7
DP: D1.6 (I/O1_2), J2.A6, J2.B6
EPD_3V3: C7.1, EPD_C5.1, J1.15, J1.16, L1.2, Q2.2 (S), TP17.TP
EPD_3V3_C: Q2.1 (G), R_CL1.1, TP13.TP, U2.18 (IO20)
EPD_BUSY: J1.9, TP9.TP, U2.26 (IO3)
EPD_CS: D6.2, J1.12, R9.1, TP10.TP, U2.11 (IO10)
EPD_DC: J1.11, TP11.TP, U2.5 (IO5)
EPD_RST: J1.10, TP12.TP, U2.21 (IO23)
FLASH_CS: D9.2, R5.1, U1.1 (!CS), U2.12 (IO11)
GDR: J1.2, Q3.1 (G), R4.2
GND: BOOT_BUTTON.1, BOOT_BUTTON.2, C1.2, C1_BAT.2, C1_BAT1.2, C1_BAT2.2, C2.2, C2_BAT.2, C3.-, C4_USB.2, C5.2, C5_USB.2, C6.2, C7.2, C8.2, C9.2, C10.2, C10_SUPERCAP.1, CHANGE_BUTTON.1, CHANGE_BUTTON.2, C_DELAY.2, D1.2 (GND), D3.1 (K), D6.1, D8.1, D9.1, D10.1, D11.1, D12.1, EPD_C1.2, EPD_C2.2, EPD_C5.2, EPD_C6.2, EPD_C7.2, EPD_C8.2, EPD_C9.2, EPD_C10.2, EPD_C11.2, EPD_C12.2, IC1.3 (GND), IC4.2 (VSS), J1.8, J1.17, J1.MP1, J1.MP2, J2.A1, J2.A12, J2.B1, J2.B12, J2.MP1, J2.MP2, J2.MP3, J2.MP4, J3.1, J4.G1 (GND_1), J4.G2 (GND_2), J4.G3 (GND_3), J4.G4 (GND_4), J4.P6 (VSS), MCP73831.2 (VSS), R1_PWRUSB.1, R2.1, R2-USB.1, R2-USB1.1, R2_BAT.1, R4.1, RESET_BUTTON.1, RESET_BUTTON.2, SENSOR2.1 (GND), SENSOR2.5 (SDO), SENSOR2.7 (GND), SJ1.1, TP4.TP, TP5.TP, U1.4 (GND), U1.9 (EXP), U2.1 (GND), U2.28 (GND), U2.29_1 (GND), U2.29_2 (GND), U2.29_3 (GND), U2.29_4 (GND), U2.29_5 (GND), U2.29_6 (GND), U2.29_7 (GND), U2.29_8 (GND), U2.29_9 (GND), U3.13 (GND), U4.1 (CTG), U4.4 (GND), U4.6 (QSTRT), U4.9 (EP)
GPIO8: R1.1, U2.10 (IO8)
I2C_PW: C1.1, C2.1, R1-PINH.2, R2-PINH.2, SENSOR2.2 (CSB), SENSOR2.6 (VDDIO), SENSOR2.8 (VDD), U2.17 (IO19)
INT_RTC: R1-PINH1.1, TP15.TP, U2.8 (IO0), U3.3 (SQW/!INT)
IO/BOOT: BOOT_BUTTON.3, BOOT_BUTTON.4, C6.1, R_BOOT.1, U2.15 (IO9)
IO/CHANGE: C10.1, CHANGE_BUTTON.3, CHANGE_BUTTON.4, R_CHANGE.1, U2.23 (IO15)
MISO: D12.2, J4.P7 (DAT0), R8.1, TP6.TP, U1.2 (DO(IO1)), U2.27 (IO2)
MOSI: D11.2, J1.14, J4.P3 (CMD), R7.1, TP7.TP, U1.5 (DI(IO0)), U2.7 (IO7)
unnamed: J2.A5, R2-USB1.2
unnamed: J2.B5, R2-USB.2
unnamed: C1_BAT1.1, D2.1 (CATHODE), IC4.1 (VIN), IC4.3 (CE), Q1.2 (S)
unnamed: C4.1, D3.2 (A), D4.1 (K)
unnamed: MCP73831.1 (STAT), R1_BAT.2
unnamed: CHG_LED.C, R1_BAT.1
unnamed: MCP73831.5 (PROG), R2_BAT.2
unnamed: EPD_C12.1, J1.24
unnamed: C_DELAY.1, IC1.5 (CT)
unnamed: EPD_C10.1, J1.22
unnamed: EPD_C8.1, J1.20
unnamed: EPD_C7.1, J1.19
unnamed: EPD_C6.1, J1.18
unnamed: EPD_C1.1, J1.4
unnamed: EPD_C2.1, J1.5
unnamed: D7.1 (CATHODE), R_CAPACITOR.1
PREVGH: D5.1 (K), EPD_C9.1, J1.21
PREVGL: D4.2 (A), EPD_C11.1, J1.23
RESE: J1.3, Q3.2 (S), R3.2
RESE': R2.2, R3.1, SJ1.2
RESET: C5.1, IC1.1 (VOUT), RESET_BUTTON.3, RESET_BUTTON.4, R_RESET.1, U2.3 (EN)
RTC_RST: U2.16 (IO18), U3.4 (!RST)
RX: TP2.TP, U2.24 (RXD0/GPIO17)
SCK: D10.2, J1.13, J4.P5 (CLK), R6.1, TP8.TP, U1.6 (CLK), U2.6 (IO6)
SCL: J3.4, R2-PINH.1, SENSOR2.4 (SCK), U2.20 (IO22), U3.16 (SCL), U4.7 (SCL)
SDA: J3.3, R1-PINH.1, SENSOR2.3 (SDI), U2.19 (IO21), U3.15 (SDA), U4.8 (SDA)
SRC: C4.2, D5.2 (A), L1.1, Q3.3 (D)
SS_SD: D8.2, J4.P2 (CD/DAT3), R10.1, U2.4 (IO4)
TX: TP1.TP, U2.25 (TXD0/GPIO16)
USB_D+: D1.1 (I/O1_1), U2.14 (IO13)
USB_D-: D1.3 (I/O2_1), U2.13 (IO12)
VBAT: C2_BAT.1, MCP73831.3 (VBAT), Q1.3 (D), TP3.TP, U4.2 (CELL), U4.3 (VDD)
VBUS: C1_BAT.1, C4_USB.1, C5_USB.1, CHG_LED.A, D1.5 (VBUS), D2.2 (ANODE), MCP73831.4 (VIN), PFMF.050.1.2, Q1.1 (G), R1_PWRUSB.2, TP14.TP
VRTC: C8.1, C10_SUPERCAP.2, R_CAPACITOR.2, U3.14 (VBAT)
VUSB: J2.A4, J2.A9, J2.B4, J2.B9, PFMF.050.1.1

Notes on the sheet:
USB C connector & ESD protection
LDO Voltage Regulator
SD Card
Display Type Selector
E-Paper Drive Circuit
Li-Po Battery Charging Controller
ESP32 C6
Battery Charge Level
Voltage Supervisor + Reset & Boot / IO Button
Environmental Sensor BME688
EPD Power
E-Paper Display Header
RTC Module DS3231SN
Test Pads
Qwiic / Stemma QT
External NORFlash64MB
SPI ESD Protection Lines
68uH

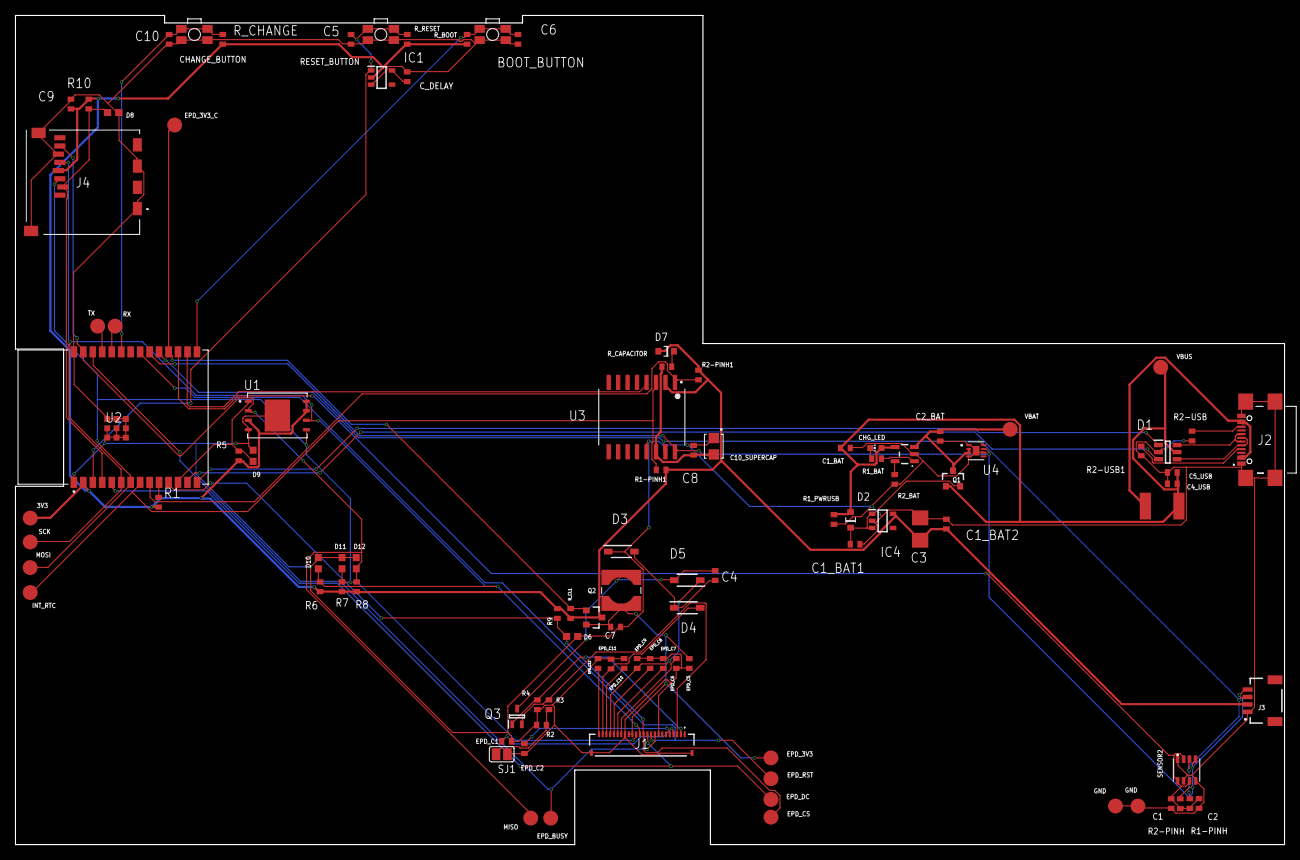
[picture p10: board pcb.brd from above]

Board: 2 copper layers, 170.2 x 111.2 mm, 103 parts (0 on the bottom side), 55 nets.

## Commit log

2025-04-06 project 2
    [PnP_proiect v34_front.csv, pcb.brd, proiect v34.csv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]
2025-04-13 issues fixed
    [BOM.csv, Pick_and_Place.csv, PnP_proiect v34_front.csv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]
2025-04-13 last issues
    [pcb.brd, schematic.sch]

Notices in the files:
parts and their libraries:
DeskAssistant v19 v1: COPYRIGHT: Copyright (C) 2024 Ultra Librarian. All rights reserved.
